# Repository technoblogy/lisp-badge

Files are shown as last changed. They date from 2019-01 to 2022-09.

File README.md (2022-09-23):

# Lisp Badge
A handheld computer with a self-contained keyboard and display that you can program in Lisp.

Version 6 updates the uLisp firmware to uLisp 4.3, adding support for arrays, and built-in documentation (see http://www.ulisp.com/show?41E0).

It also adds some extra key combinations to allow you to enter additional characters from the keyboard:

| Character | Combination |
| --- | --- |
| ~  | Shift+ESC |
| % | Shift+DEL |
| : | Shift+ENTER |
| ? | Shift+SPACE |

For information about building the Lisp Badge see: http://www.technoblogy.com/show?2AEE

For information about programming the Lisp badge see: http://www.ulisp.com/show?2L0C

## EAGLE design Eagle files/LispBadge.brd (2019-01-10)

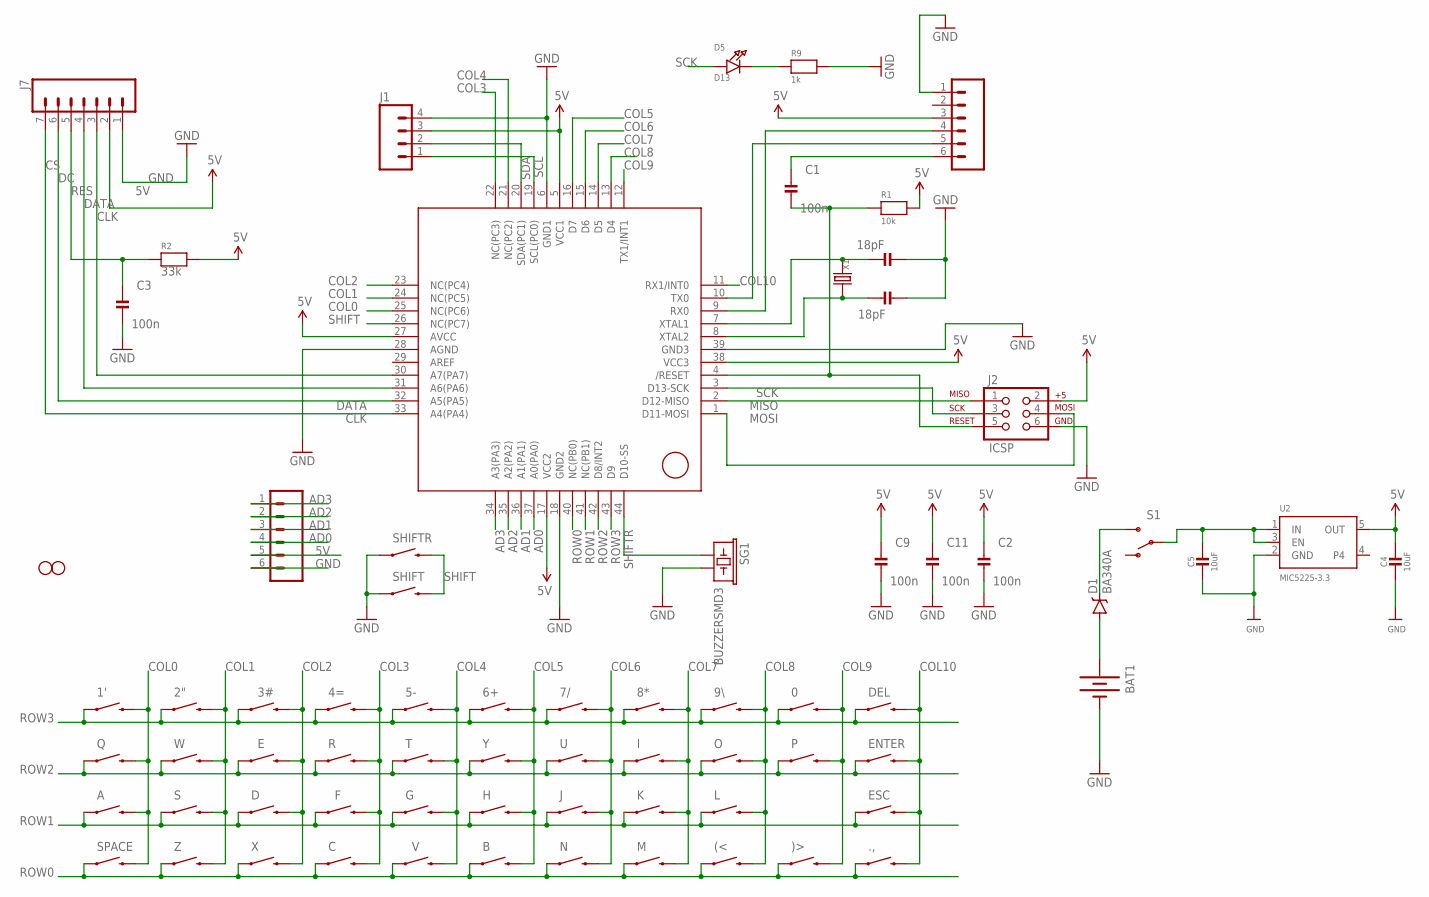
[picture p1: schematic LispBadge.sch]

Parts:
0, 1', 2", 3#, 4=, 5-, 6+, 7/, 8*, 9\\, .,: SWITCH-MOMENTARY-2PTH; TACTILE-PTH
(<: SWITCH-MOMENTARY-2PTH; TACTILE-PTH
)>: SWITCH-MOMENTARY-2PTH; TACTILE-PTH
A: SWITCH-MOMENTARY-2PTH; TACTILE-PTH
B: SWITCH-MOMENTARY-2PTH; TACTILE-PTH
BAT1: BATTERYAAA-KIT; BATTERY-AAA-KIT
C: SWITCH-MOMENTARY-2PTH; TACTILE-PTH
C1, C2, C3, C9, C11: 100n; _0805MP
C4, C5: 10uF; 0805-NO
C12, C13: 18pF; _0805MP
D: SWITCH-MOMENTARY-2PTH; TACTILE-PTH
D1: BA340A; SMA-DIODE
D5: D13; CHIPLED_0805_NOOUTLINE
DEL: SWITCH-MOMENTARY-2PTH; TACTILE-PTH
E: SWITCH-MOMENTARY-2PTH; TACTILE-PTH
ENTER: SWITCH-MOMENTARY-2PTH; TACTILE-PTH
ESC: SWITCH-MOMENTARY-2PTH; TACTILE-PTH
F: SWITCH-MOMENTARY-2PTH; TACTILE-PTH
G: SWITCH-MOMENTARY-2PTH; TACTILE-PTH
H: SWITCH-MOMENTARY-2PTH; TACTILE-PTH
I: SWITCH-MOMENTARY-2PTH; TACTILE-PTH
J: SWITCH-MOMENTARY-2PTH; TACTILE-PTH
J1: M04LONGPADS; 1X04_LONGPADS
J2: ICSP; 2X3
J7: M07; 1X07
JP1, JP11: M06LONGPADS; 1X06_LONGPADS
JP4, JP5: STAND-OFF
K: SWITCH-MOMENTARY-2PTH; TACTILE-PTH
L: SWITCH-MOMENTARY-2PTH; TACTILE-PTH
M: SWITCH-MOMENTARY-2PTH; TACTILE-PTH
N: SWITCH-MOMENTARY-2PTH; TACTILE-PTH
O: SWITCH-MOMENTARY-2PTH; TACTILE-PTH
P: SWITCH-MOMENTARY-2PTH; TACTILE-PTH
Q: SWITCH-MOMENTARY-2PTH; TACTILE-PTH
R: SWITCH-MOMENTARY-2PTH; TACTILE-PTH
R1: 10k; _0805MP
R2: 33k; _0805MP
R9: 1k; _0805MP
S: SWITCH-MOMENTARY-2PTH; TACTILE-PTH
S1: SWITCH-SPDTPTH; SWITCH-SPDT
SG1: BUZZERSMD3; BUZZER-CMT1102
SHIFT: SWITCH-MOMENTARY-2PTH; TACTILE-PTH
SHIFTR: SWITCH-MOMENTARY-2PTH; TACTILE-PTH
SPACE: SWITCH-MOMENTARY-2PTH; TACTILE-PTH
T: SWITCH-MOMENTARY-2PTH; TACTILE-PTH
U: SWITCH-MOMENTARY-2PTH; TACTILE-PTH
U2: MIC5225-3.3; SOT23-5
U3: ATMEGA1284P; TQFP44
V: SWITCH-MOMENTARY-2PTH; TACTILE-PTH
W: SWITCH-MOMENTARY-2PTH; TACTILE-PTH
X: SWITCH-MOMENTARY-2PTH; TACTILE-PTH
X1: CRYSTAL-0500290P1; 2P-SMD-5.0X3.2
Y: SWITCH-MOMENTARY-2PTH; TACTILE-PTH
Z: SWITCH-MOMENTARY-2PTH; TACTILE-PTH

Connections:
5V: C2.1, C4.1, C9.1, C11.1, J1.3, J2.2, J7.2, JP1.3, JP11.5, R1.2, R2.2, U2.5 (OUT), U3.5 (VCC1), U3.17 (VCC2), U3.27 (AVCC), U3.38 (VCC3)
AD0: JP11.4, U3.37 (A0(PA0))
AD1: JP11.3, U3.36 (A1(PA1))
AD2: JP11.2, U3.35 (A2(PA2))
AD3: JP11.1, U3.34 (A3(PA3))
CLK: J7.3, U3.30 (A7(PA7))
COL0: 1'.3 (2), A.3 (2), Q.3 (2), SPACE.3 (2), U3.25 (NC(PC6))
COL1: 2".3 (2), S.3 (2), U3.24 (NC(PC5)), W.3 (2), Z.3 (2)
COL2: 3#.3 (2), D.3 (2), E.3 (2), U3.23 (NC(PC4)), X.3 (2)
COL3: 4=.3 (2), C.3 (2), F.3 (2), R.3 (2), U3.22 (NC(PC3))
COL4: 5-.3 (2), G.3 (2), T.3 (2), U3.21 (NC(PC2)), V.3 (2)
COL5: 6+.3 (2), B.3 (2), H.3 (2), U3.16 (D7), Y.3 (2)
COL6: 7/.3 (2), J.3 (2), N.3 (2), U.3 (2), U3.15 (D6)
COL7: 8*.3 (2), I.3 (2), K.3 (2), M.3 (2), U3.14 (D5)
COL8: 9\\.3 (2), (<.3 (2), L.3 (2), O.3 (2), U3.13 (D4)
COL9: 0.3 (2), )>.3 (2), P.3 (2), U3.12 (TX1/INT1)
COL10: .,.3 (2), DEL.3 (2), ENTER.3 (2), ESC.3 (2), U3.11 (RX1/INT0)
CS: J7.7, U3.33 (A4(PA4))
DATA: J7.4, U3.31 (A6(PA6))
DC: J7.6, U3.32 (A5(PA5))
GND: BAT1.GND@1 (-), C2.2, C3.2, C4.2, C5.2, C9.2, C11.2, C12.1, C13.1, J1.4, J2.6, J7.1, JP1.1, JP11.6, R9.2, SG1.2, SHIFT.1, SHIFTR.1, U2.2 (GND), U3.6 (GND1), U3.18 (GND2), U3.28 (AGND), U3.39 (GND3)
MISO: J2.1, U3.2 (D12-MISO)
MOSI: J2.4, U3.1 (D11-MOSI)
unnamed: BAT1.PWR@1 (+), D1.A
unnamed: D1.C, S1.3 (S)
unnamed: D5.C, R9.1
unnamed: C5.1, S1.2, U2.1 (IN), U2.3 (EN)
unnamed: C13.2, U3.8 (XTAL2), X1.2
unnamed: C12.2, U3.7 (XTAL1), X1.1
unnamed: C1.2, J2.5, R1.1, U3.4 (/RESET)
unnamed: C1.1, JP1.6
RES: C3.1, J7.5, R2.1
ROW0: (<.1, )>.1, .,.1, B.1, C.1, M.1, N.1, SPACE.1, U3.40 (NC(PB0)), V.1, X.1, Z.1
ROW1: A.1, D.1, ESC.1, F.1, G.1, H.1, J.1, K.1, L.1, S.1, U3.41 (NC(PB1))
ROW2: E.1, ENTER.1, I.1, O.1, P.1, Q.1, R.1, T.1, U.1, U3.42 (D8/INT2), W.1, Y.1
ROW3: 0.1, 1'.1, 2".1, 3#.1, 4=.1, 5-.1, 6+.1, 7/.1, 8*.1, 9\\.1, DEL.1, U3.43 (D9)
RX-I: JP1.4, U3.9 (RX0)
SCK: D5.A, J2.3, U3.3 (D13-SCK)
SCL: J1.1, U3.19 (SCL(PC0))
SDA: J1.2, U3.20 (SDA(PC1))
SHIFT: SHIFT.3 (2), SHIFTR.3 (2), U3.26 (NC(PC7))
SHIFTR: SG1.1, U3.44 (D10-SS)
TX-O: JP1.5, U3.10 (TX0)

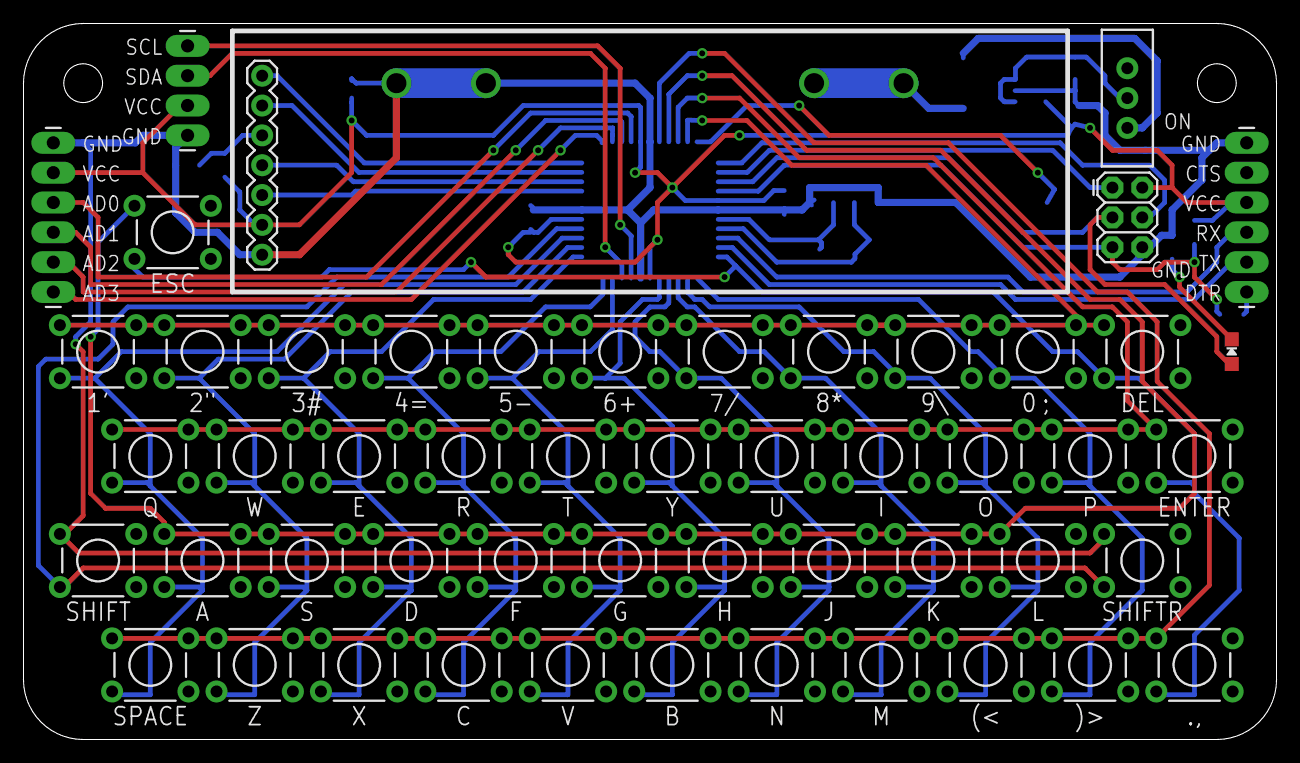
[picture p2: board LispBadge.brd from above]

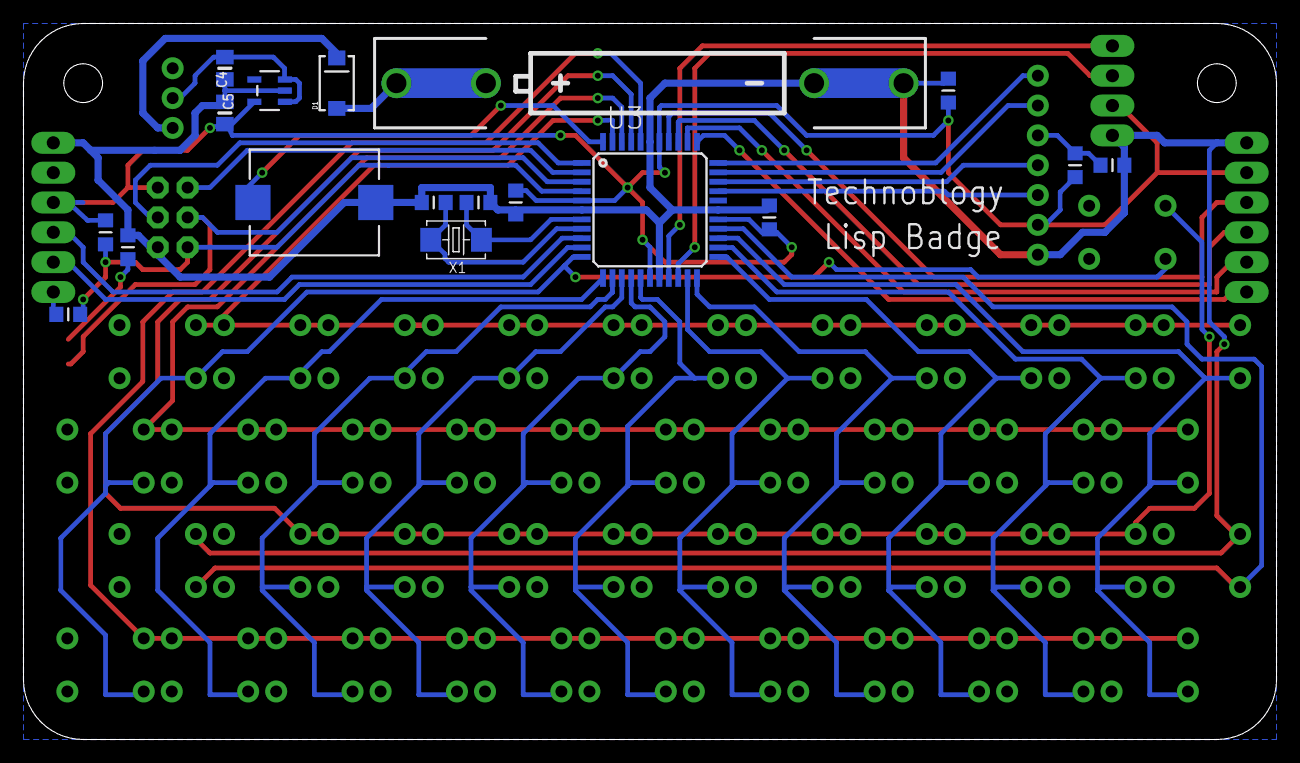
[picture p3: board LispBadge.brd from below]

Board: 2 copper layers, 106.7 x 61.0 mm, 72 parts (18 on the bottom side), 43 nets.

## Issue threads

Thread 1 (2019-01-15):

Schematic for those who are not using Eagle

fdufnews, 2019-01-15:
Hi,
Thanks a lot for this design but can you put a schematic in pdf format for those that are not using eagle.
When comparing the code in this repo and the schematic on technoblogy it seems there are differences (on shiftr for example).
A fast search with a text editor seems to confirm that shiftr is connected to D10-SS. Am I right?
Best regards
fdufnews

technoblogy, 2019-01-15:
The left and right SHIFT keys both connect between PC7 and GND. The label SHIFTR on D10 on the Eagle schematic is a mistake, and should be removed.

The schematic on Technoblogy was generated from the Eagle schematic, and then tidied up by hand. It corrects some errors that don't affect the PCB. Which one would you like as a PDF?

fdufnews, 2019-01-15:
Ok, thanks you for the answer.
So the second part of the test at line 3882 is no more necessary
```
  // Check rows and shift keys
  shift = ((PINC & 1<<PINC7) && (PINB & 1<<PINB4)) ? 0 : 1;
```
I am analysing the code because I want to use the keyboard of an Xbox chatpad and the matrix is different from the one you are using.

technoblogy, 2019-01-15:
You’re correct. The previous version of the circuit had the SHIFT keys on two separate inputs, but I decided to add a piezo speaker on PB4, so that line should change to:

  shift = (PINC & 1<<PINC7) ? 0 : 1;

Also, remove this line in InitKybd():

  PORTB = PORTB | 1<<PINB4;

Thanks for spotting that. I’ll update the code.

Regards,
David

+------------------------------------------------------------+
David Johnson-Davies, Human-Computer Interface Ltd
17 Signet Court, Swanns Road, Cambridge, CB5 8LA, England.

Tel: +44 1223 314934, Fax: +44 1223 462562
Email: david@interface.co.uk, Web: http://www.interface.co.uk/
+------------------------------------------------------------+

Closed 2019-01-15.

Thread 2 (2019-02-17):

playNote() not working

Odingod, 2019-02-17:
Hi

 and thanks for the design!

I noticed that the note function isn't working. I checked the code and found this
```
if (pin == 14) {
    DDRD = DDRD | 1<<DDD6; // PD6 (Arduino D14) as output
    TCCR2A = 0<<COM2A0 | 1<<COM2B0 | 2<<WGM20; // Toggle OC2B on match
  } else if (pin == 15) {
    DDRD = DDRD | 1<<DDD7; // PD7 (Arduino D15) as output
    TCCR2A = 1<<COM2A0 | 0<<COM2B0 | 2<<WGM20; // Toggle OC2A on match
  } else error(PSTR("'note' pin not supported"));
```

Shouldn't there be pin PB4 in there?

I tried changing it to this
```
  if (pin == 10) {
    DDRB = DDRB | 1<<DDB4; // PB4 (Arduino D10) as output
    TCCR2A = 1<<COM2A0 | 0<<COM2B0 | 2<<WGM20; // Toggle OC2A on match
  } else error(PSTR("'note' pin not supported"));
```

but it didn't work. I'm not that familiar with the registers used so that might be the problem.

The symptoms of this are, that the keyboard stops working in both cases when I either call (note 14 0 4) or (note 10 0 4). The serial communication works fine though.

technoblogy, 2019-02-17:
Unfortunately you can't use the uLisp **note** function with the Lisp Badge because on the ATmega1284P **note** uses pins PD6 or PD7, and these are used for the keyboard on the Lisp Badge. Perhaps this could be solved in a future version of the PCB. In the meantime Version 1c allows you to play a "beep" through the speaker with (princ #\beep).

Odingod, 2019-02-17:
Okay, I'll write a simpler note function with tone.

Thanks for the quick response and for the badge!
P.S.
I couldn't get the beep working, I get both unknown character and incomplete list errors with that.

technoblogy, 2019-02-17:
Sorry, I meant: (princ #\bell).

PS Glad you got the badge working; I'd love to see a photo of it!

Odingod, 2019-02-17:
Here's a bad photo http://i65.tinypic.com/11ioies.jpg. The screen is not blurry at all.

technoblogy, 2019-02-17:
Great! Nice job.

Closed 2019-02-17.

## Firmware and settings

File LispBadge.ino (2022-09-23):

/* Lisp Badge - uLisp 4.3
   David Johnson-Davies - www.technoblogy.com - 22nd September 2022

   Licensed under the MIT license: https://opensource.org/licenses/MIT
*/

// Lisp Library
const char LispLibrary[] PROGMEM = "";

// Compile options

#define checkoverflow
// #define resetautorun
#define printfreespace
#define serialmonitor
// #define printgcs
// #define sdcardsupport
// #define lisplibrary

// Includes

// #include "LispLibrary.h"
#include <avr/sleep.h>
#include <setjmp.h>
#include <SPI.h>
#include <limits.h>
#include <EEPROM.h>

#if defined(sdcardsupport)
#include <SD.h>
#define SDSIZE 172
#else
#define SDSIZE 0
#endif

// Workspace - sizes in bytes
#define WORDALIGNED __attribute__((aligned (2)))
#define OBJECTALIGNED __attribute__((aligned (4)))
#define BUFFERSIZE 21                     /* longest builtin name + 1 */

#if defined(__AVR_ATmega1284P__)
  #include "optiboot.h"
  #define WORKSPACESIZE (2848-SDSIZE)     /* Objects (4*bytes) */
//  #define EEPROMSIZE 4096                 /* Bytes */
  #define FLASHWRITESIZE 16384            /* Bytes */
  #define CODESIZE 96                     /* Bytes <= 256 */
  #define STACKDIFF 320
  #define CPU_ATmega1284P

#else
#error "Board not supported!"
#endif

// C Macros

#define nil                NULL
#define car(x)             (((object *) (x))->car)
#define cdr(x)             (((object *) (x))->cdr)

#define first(x)           (((object *) (x))->car)
#define second(x)          (car(cdr(x)))
#define cddr(x)            (cdr(cdr(x)))
#define third(x)           (car(cdr(cdr(x))))

#define push(x, y)         ((y) = cons((x),(y)))
#define pop(y)             ((y) = cdr(y))

#define integerp(x)        ((x) != NULL && (x)->type == NUMBER)
#define symbolp(x)         ((x) != NULL && (x)->type == SYMBOL)
#define stringp(x)         ((x) != NULL && (x)->type == STRING)
#define characterp(x)      ((x) != NULL && (x)->type == CHARACTER)
#define arrayp(x)          ((x) != NULL && (x)->type == ARRAY)
#define streamp(x)         ((x) != NULL && (x)->type == STREAM)

#define mark(x)            (car(x) = (object *)(((uintptr_t)(car(x))) | MARKBIT))
#define unmark(x)          (car(x) = (object *)(((uintptr_t)(car(x))) & ~MARKBIT))
#define marked(x)          ((((uintptr_t)(car(x))) & MARKBIT) != 0)
#define MARKBIT            1

#define setflag(x)         (Flags = Flags | 1<<(x))
#define clrflag(x)         (Flags = Flags & ~(1<<(x)))
#define tstflag(x)         (Flags & 1<<(x))

#define issp(x)            (x == ' ' || x == '\n' || x == '\r' || x == '\t')
#define longsymbolp(x)     (((x)->name & 0x03) == 0)
#define twist(x)           ((uint16_t)((x)<<2) | (((x) & 0xC000)>>14))
#define untwist(x)         (((x)>>2 & 0x3FFF) | ((x) & 0x03)<<14)
#define PACKEDS            17600
#define BUILTINS           64000

// Code marker stores start and end of code block (max 256 bytes)
#define startblock(x)      ((x->integer) & 0xFF)
#define endblock(x)        ((x->integer) >> 8 & 0xFF)

#define SDCARD_SS_PIN 10

#if defined(CPU_ATmega4809)
#define PROGMEM
#define PSTR(s) (s)
#endif

// Constants

const int TRACEMAX = 3; // Number of traced functions
enum type { ZZERO=0, SYMBOL=2, CODE=4, NUMBER=6, STREAM=8, CHARACTER=10, ARRAY=12, STRING=14, PAIR=16 };  // ARRAY STRING and PAIR must be last
enum token { UNUSED, BRA, KET, QUO, DOT };
enum stream { SERIALSTREAM, I2CSTREAM, SPISTREAM, SDSTREAM, STRINGSTREAM };

// Stream names used by printobject
const char serialstream[] PROGMEM = "serial";
const char i2cstream[] PROGMEM = "i2c";
const char spistream[] PROGMEM = "spi";
const char sdstream[] PROGMEM = "sd";
PGM_P const streamname[] PROGMEM = {serialstream, i2cstream, spistream, sdstream};

// Typedefs

typedef unsigned int symbol_t;

typedef struct sobject {
  union {
    struct {
      sobject *car;
      sobject *cdr;
    };
    struct {
      unsigned int type;
      union {
        symbol_t name;
        int integer;
        int chars; // For strings
      };
    };
  };
} object;

typedef object *(*fn_ptr_type)(object *, object *);
typedef void (*mapfun_t)(object *, object **);
typedef int (*intfn_ptr_type)(int w, int x, int y, int z);

typedef const struct {
  const char *string;
  fn_ptr_type fptr;
  uint8_t minmax;
  const char *doc;
} tbl_entry_t;

typedef int (*gfun_t)();
typedef void (*pfun_t)(char);

enum builtin_t { NIL, TEE, NOTHING, OPTIONAL, INITIALELEMENT, ELEMENTTYPE, BIT, AMPREST, LAMBDA, LET,
LETSTAR, CLOSURE, PSTAR, SPECIAL_FORMS, QUOTE, OR, DEFUN, DEFVAR, SETQ, LOOP, RETURN, PUSH, POP, INCF,
DECF, SETF, DOLIST, DOTIMES, TRACE, UNTRACE, FORMILLIS, TIME, WITHSERIAL, WITHI2C, WITHSPI, WITHSDCARD,
DEFCODE, TAIL_FORMS, PROGN, IF, COND, WHEN, UNLESS, CASE, AND, HELP, FUNCTIONS, NOT, NULLFN, CONS, ATOM,
LISTP, CONSP, SYMBOLP, BOUNDP, SETFN, STREAMP, EQ, CAR, FIRST, CDR, REST, CAAR, CADR, SECOND, CDAR, CDDR,
CAAAR, CAADR, CADAR, CADDR, THIRD, CDAAR, CDADR, CDDAR, CDDDR, LENGTH, ARRAYDIMENSIONS, LIST, MAKEARRAY,
REVERSE, NTH, AREF, ASSOC, MEMBER, APPLY, FUNCALL, APPEND, MAPC, MAPCAR, MAPCAN, ADD, SUBTRACT, MULTIPLY,
DIVIDE, TRUNCATE, MOD, ONEPLUS, ONEMINUS, ABS, RANDOM, MAXFN, MINFN, NOTEQ, NUMEQ, LESS, LESSEQ, GREATER,
GREATEREQ, PLUSP, MINUSP, ZEROP, ODDP, EVENP, INTEGERP, NUMBERP, CHAR, CHARCODE, CODECHAR, CHARACTERP,
STRINGP, STRINGEQ, STRINGLESS, STRINGGREATER, SORT, STRINGFN, CONCATENATE, SUBSEQ, READFROMSTRING,
PRINCTOSTRING, PRIN1TOSTRING, LOGAND, LOGIOR, LOGXOR, LOGNOT, ASH, LOGBITP, EVAL, GLOBALS, LOCALS,
MAKUNBOUND, BREAK, READ, PRIN1, PRINT, PRINC, TERPRI, READBYTE, READLINE, WRITEBYTE, WRITESTRING,
WRITELINE, RESTARTI2C, GC, ROOM, SAVEIMAGE, LOADIMAGE, CLS, PINMODE, DIGITALREAD, DIGITALWRITE,
ANALOGREAD, ANALOGREFERENCE, ANALOGREADRESOLUTION, ANALOGWRITE, DACREFERENCE, DELAY, MILLIS, SLEEP, NOTE,
REGISTER, EDIT, PPRINT, PPRINTALL, FORMAT, REQUIRE, LISTLIBRARY, DOCUMENTATION, PLOT, PLOT3D, GLYPHPIXEL,
PLOTPIXEL, FILLSCREEN, KEYWORDS, 
#if defined(CPU_ATmega1284P)
K_HIGH, K_LOW, K_INPUT, K_INPUT_PULLUP, K_OUTPUT, K_DEFAULT, K_INTERNAL1V1, K_INTERNAL2V56, K_EXTERNAL,
#endif
USERFUNCTIONS, ENDFUNCTIONS, SET_SIZE = INT_MAX };

// Global variables

object Workspace[WORKSPACESIZE] OBJECTALIGNED;
#if defined(CODESIZE)
uint8_t MyCode[CODESIZE] WORDALIGNED; // Must be even
#endif

jmp_buf exception;
unsigned int Freespace = 0;
object *Freelist;
unsigned int I2Ccount;
unsigned int TraceFn[TRACEMAX];
unsigned int TraceDepth[TRACEMAX];

object *GlobalEnv;
object *GCStack = NULL;
object *GlobalString;
object *GlobalStringTail;
int GlobalStringIndex = 0;
uint8_t PrintCount = 0;
uint8_t BreakLevel = 0;
char LastChar = 0;
char LastPrint = 0;
uint16_t RandomSeed;

// Flags
enum flag { PRINTREADABLY, RETURNFLAG, ESCAPE, EXITEDITOR, LIBRARYLOADED, NOESC, NOECHO };
volatile uint8_t Flags = 0b00001; // PRINTREADABLY set by default

// Forward references
object *tee;
void pfstring (PGM_P s, pfun_t pfun);

// Error handling

void errorsub (symbol_t fname, PGM_P string) {
  pfl(pserial); pfstring(PSTR("Error: "), pserial);
  if (fname != sym(NIL)) {
    pserial('\'');
    psymbol(fname, pserial);
    pserial('\''); pserial(' ');
  }
  pfstring(string, pserial);
}

void errorsym (symbol_t fname, PGM_P string, object *symbol) {
  errorsub(fname, string);
  pserial(':'); pserial(' ');
  printobject(symbol, pserial);
  errorend();
}

void errorsym2 (symbol_t fname, PGM_P string) {
  errorsub(fname, string);
  errorend();
}

void error (builtin_t fname, PGM_P string, object *symbol) {
  errorsym(sym(fname), string, symbol);
}

void error2 (builtin_t fname, PGM_P string) {
  errorsym2(sym(fname), string);
}

void errorend () { pln(pserial); GCStack = NULL; longjmp(exception, 1); }

void formaterr (object *formatstr, PGM_P string, uint8_t p) {
  pln(pserial); indent(4, ' ', pserial); printstring(formatstr, pserial); pln(pserial);
  indent(p+5, ' ', pserial); pserial('^');
  error2(FORMAT, string);
  pln(pserial);
  GCStack = NULL;
  longjmp(exception, 1);
}

// Save space as these are used multiple times
const char notanumber[] PROGMEM = "argument is not a number";
const char notaninteger[] PROGMEM = "argument is not an integer";
const char notastring[] PROGMEM = "argument is not a string";
const char notalist[] PROGMEM = "argument is not a list";
const char notasymbol[] PROGMEM = "argument is not a symbol";
const char notproper[] PROGMEM = "argument is not a proper list";
const char toomanyargs[] PROGMEM = "too many arguments";
const char toofewargs[] PROGMEM = "too few arguments";
const char noargument[] PROGMEM = "missing argument";
const char nostream[] PROGMEM = "missing stream argument";
const char overflow[] PROGMEM = "arithmetic overflow";
const char divisionbyzero[] PROGMEM = "division by zero";
const char indexnegative[] PROGMEM = "index can't be negative";
const char invalidarg[] PROGMEM = "invalid argument";
const char invalidkey[] PROGMEM = "invalid keyword";
const char illegalclause[] PROGMEM = "illegal clause";
const char invalidpin[] PROGMEM = "invalid pin";
const char oddargs[] PROGMEM = "odd number of arguments";
const char indexrange[] PROGMEM = "index out of range";
const char canttakecar[] PROGMEM = "can't take car";
const char canttakecdr[] PROGMEM = "can't take cdr";
const char unknownstreamtype[] PROGMEM = "unknown stream type";

// Set up workspace

void initworkspace () {
  Freelist = NULL;
  for (int i=WORKSPACESIZE-1; i>=0; i--) {
    object *obj = &Workspace[i];
    car(obj) = NULL;
    cdr(obj) = Freelist;
    Freelist = obj;
    Freespace++;
  }
}

object *myalloc () {
  if (Freespace == 0) error2(NIL, PSTR("no room"));
  object *temp = Freelist;
  Freelist = cdr(Freelist);
  Freespace--;
  return temp;
}

inline void myfree (object *obj) {
  car(obj) = NULL;
  cdr(obj) = Freelist;
  Freelist = obj;
  Freespace++;
}

// Make each type of object

object *number (int n) {
  object *ptr = myalloc();
  ptr->type = NUMBER;
  ptr->integer = n;
  return ptr;
}

object *character (uint8_t c) {
  object *ptr = myalloc();
  ptr->type = CHARACTER;
  ptr->chars = c;
  return ptr;
}

object *cons (object *arg1, object *arg2) {
  object *ptr = myalloc();
  ptr->car = arg1;
  ptr->cdr = arg2;
  return ptr;
}

object *symbol (symbol_t name) {
  object *ptr = myalloc();
  ptr->type = SYMBOL;
  ptr->name = name;
  return ptr;
}

inline object *bsymbol (builtin_t name) {
  return intern(twist(name+BUILTINS));
}

object *codehead (int entry) {
  object *ptr = myalloc();
  ptr->type = CODE;
  ptr->integer = entry;
  return ptr;
}

object *intern (symbol_t name) {
  for (int i=0; i<WORKSPACESIZE; i++) {
    object *obj = &Workspace[i];
    if (obj->type == SYMBOL && obj->name == name) return obj;
  }
  return symbol(name);
}

bool eqsymbols (object *obj, char *buffer) {
  object *arg = cdr(obj);
  int i = 0;
  while (!(arg == NULL && buffer[i] == 0)) {
    if (arg == NULL || buffer[i] == 0 || arg->chars != (buffer[i]<<8 | buffer[i+1])) return false;
    arg = car(arg);
    i = i + 2;
  }
  return true;
}

object *internlong (char *buffer) {
  for (int i=0; i<WORKSPACESIZE; i++) {
    object *obj = &Workspace[i];
    if (obj->type == SYMBOL && longsymbolp(obj) && eqsymbols(obj, buffer)) return obj;
  }
  object *obj = lispstring(buffer);
  obj->type = SYMBOL;
  return obj;
}

object *stream (uint8_t streamtype, uint8_t address) {
  object *ptr = myalloc();
  ptr->type = STREAM;
  ptr->integer = streamtype<<8 | address;
  return ptr;
}

object *newstring () {
  object *ptr = myalloc();
  ptr->type = STRING;
  ptr->chars = 0;
  return ptr;
}

// Garbage collection

void markobject (object *obj) {
  MARK:
  if (obj == NULL) return;
  if (marked(obj)) return;

  object* arg = car(obj);
  unsigned int type = obj->type;
  mark(obj);

  if (type >= PAIR || type == ZZERO) { // cons
    markobject(arg);
    obj = cdr(obj);
    goto MARK;
  }

  if (type == ARRAY) {
    obj = cdr(obj);
    goto MARK;
  }

  if ((type == STRING) || (type == SYMBOL && longsymbolp(obj))) {
    obj = cdr(obj);
    while (obj != NULL) {
      arg = car(obj);
      mark(obj);
      obj = arg;
    }
  }
}

void sweep () {
  Freelist = NULL;
  Freespace = 0;
  for (int i=WORKSPACESIZE-1; i>=0; i--) {
    object *obj = &Workspace[i];
    if (!marked(obj)) myfree(obj); else unmark(obj);
  }
}

void gc (object *form, object *env) {
  #if defined(printgcs)
  int start = Freespace;
  #endif
  markobject(tee);
  markobject(GlobalEnv);
  markobject(GCStack);
  markobject(form);
  markobject(env);
  sweep();
  #if defined(printgcs)
  pfl(pserial); pserial('{'); pint(Freespace - start, pserial); pserial('}');
  #endif
}

// Compact image

void movepointer (object *from, object *to) {
  for (int i=0; i<WORKSPACESIZE; i++) {
    object *obj = &Workspace[i];
    unsigned int type = (obj->type) & ~MARKBIT;
    if (marked(obj) && (type >= ARRAY || type==ZZERO || (type == SYMBOL && longsymbolp(obj)))) {
      if (car(obj) == (object *)((uintptr_t)from | MARKBIT))
        car(obj) = (object *)((uintptr_t)to | MARKBIT);
      if (cdr(obj) == from) cdr(obj) = to;
    }
  }
  // Fix strings and long symbols
  for (int i=0; i<WORKSPACESIZE; i++) {
    object *obj = &Workspace[i];
    if (marked(obj)) {
      unsigned int type = (obj->type) & ~MARKBIT;
      if (type == STRING || (type == SYMBOL && longsymbolp(obj))) {
        obj = cdr(obj);
        while (obj != NULL) {
          if (cdr(obj) == to) cdr(obj) = from;
          obj = (object *)((uintptr_t)(car(obj)) & ~MARKBIT);
        }
      }
    }
  }
}

uintptr_t compactimage (object **arg) {
  markobject(tee);
  markobject(GlobalEnv);
  markobject(GCStack);
  object *firstfree = Workspace;
  while (marked(firstfree)) firstfree++;
  object *obj = &Workspace[WORKSPACESIZE-1];
  while (firstfree < obj) {
    if (marked(obj)) {
      car(firstfree) = car(obj);
      cdr(firstfree) = cdr(obj);
      unmark(obj);
      movepointer(obj, firstfree);
      if (GlobalEnv == obj) GlobalEnv = firstfree;
      if (GCStack == obj) GCStack = firstfree;
      if (*arg == obj) *arg = firstfree;
      while (marked(firstfree)) firstfree++;
    }
    obj--;
  }
  sweep();
  return firstfree - Workspace;
}

// Make SD card filename

char *MakeFilename (object *arg, char *buffer) {
  int max = BUFFERSIZE-1;
  int i = 0;
  do {
    char c = nthchar(arg, i);
    if (c == '\0') break;
    buffer[i++] = c;
  } while (i<max);
  buffer[i] = '\0';
  return buffer;
}

// Save-image and load-image

#if defined(sdcardsupport)
void SDWriteInt (File file, int data) {
  file.write(data & 0xFF); file.write(data>>8 & 0xFF);
}

int SDReadInt (File file) {
  uint8_t b0 = file.read(); uint8_t b1 = file.read();
  return b0 | b1<<8;
}
#elif defined(FLASHWRITESIZE)
#if defined (CPU_ATmega1284P)
// save-image area is the 16K bytes (64 256-byte pages) from 0x1bc00 to 0x1fc00
const uint32_t BaseAddress = 0x1bc00;
uint8_t FlashCheck() {
  return 0;
}

void FlashWriteInt (uint32_t *addr, int data) {
  if (((*addr) & 0xFF) == 0) optiboot_page_erase(BaseAddress + ((*addr) & 0xFF00));
  optiboot_page_fill(BaseAddress + *addr, data);
  if (((*addr) & 0xFF) == 0xFE) optiboot_page_write(BaseAddress + ((*addr) & 0xFF00));
  (*addr)++; (*addr)++;
}

void FlashEndWrite (uint32_t *addr) {
  if (((*addr) & 0xFF) != 0) optiboot_page_write((BaseAddress + ((*addr) & 0xFF00)));
}

uint8_t FlashReadByte (uint32_t *addr) {
  return pgm_read_byte_far(BaseAddress + (*addr)++);
}

int FlashReadInt (uint32_t *addr) {
  int data = pgm_read_word_far(BaseAddress + *addr);
  (*addr)++; (*addr)++;
  return data;
}
#elif defined (CPU_AVR128DX48)
// save-image area is the 16K bytes (32 512-byte pages) from 0x1c000 to 0x20000
const uint32_t BaseAddress = 0x1c000;
uint8_t FlashCheck() {
  return Flash.checkWritable();
}

void FlashWriteInt (uint32_t *addr, int data) {
  if (((*addr) & 0x1FF) == 0) Flash.erasePage(BaseAddress + ((*addr) & 0xFE00));
  Flash.writeWord(BaseAddress + *addr, data);
  (*addr)++; (*addr)++;
}

void FlashEndWrite (uint32_t *addr) {
  (void) addr;
}

uint8_t FlashReadByte (uint32_t *addr) {
  return Flash.readByte(BaseAddress + (*addr)++);
}

int FlashReadInt (uint32_t *addr) {
  int data = Flash.readWord(BaseAddress + *addr);
  (*addr)++; (*addr)++;
  return data;
}
#endif
#else
void EEPROMWriteInt (unsigned int *addr, int data) {
  EEPROM.write((*addr)++, data & 0xFF); EEPROM.write((*addr)++, data>>8 & 0xFF);
}

int EEPROMReadInt (unsigned int *addr) {
  uint8_t b0 = EEPROM.read((*addr)++); uint8_t b1 = EEPROM.read((*addr)++);
  return b0 | b1<<8;
}
#endif

unsigned int saveimage (object *arg) {
  unsigned int imagesize = compactimage(&arg);
#if defined(sdcardsupport)
  SD.begin(SDCARD_SS_PIN);
  File file;
  if (stringp(arg)) {
    char buffer[BUFFERSIZE];
    file = SD.open(MakeFilename(arg, buffer), O_RDWR | O_CREAT | O_TRUNC);
    if (!file) error2(SAVEIMAGE, PSTR("problem saving to SD card or invalid filename"));
    arg = NULL;
  } else if (arg == NULL || listp(arg)) {
    file = SD.open("/ULISP.IMG", O_RDWR | O_CREAT | O_TRUNC);
    if (!file) error2(SAVEIMAGE, PSTR("problem saving to SD card"));
  }
  else error(SAVEIMAGE, invalidarg, arg);
  SDWriteInt(file, (uintptr_t)arg);
  SDWriteInt(file, imagesize);
  SDWriteInt(file, (uintptr_t)GlobalEnv);
  SDWriteInt(file, (uintptr_t)GCStack);
  #if defined(CODESIZE)
  for (int i=0; i<CODESIZE; i++) file.write(MyCode[i]);
  #endif
  for (unsigned int i=0; i<imagesize; i++) {
    object *obj = &Workspace[i];
    SDWriteInt(file, (uintptr_t)car(obj));
    SDWriteInt(file, (uintptr_t)cdr(obj));
  }
  file.close();
  return imagesize;
#elif defined(FLASHWRITESIZE)
  if (!(arg == NULL || listp(arg))) error(SAVEIMAGE, invalidarg, arg);
  if (FlashCheck()) error2(SAVEIMAGE, PSTR("flash write not supported"));
  // Save to Flash
  int bytesneeded = 10 + CODESIZE + imagesize*4;
  if (bytesneeded > FLASHWRITESIZE) error(SAVEIMAGE, PSTR("image too large"), number(imagesize));
  uint32_t addr = 0;
  FlashWriteInt(&addr, (uintptr_t)arg);
  FlashWriteInt(&addr, imagesize);
  FlashWriteInt(&addr, (uintptr_t)GlobalEnv);
  FlashWriteInt(&addr, (uintptr_t)GCStack);
  #if defined(CODESIZE)
  for (int i=0; i<CODESIZE/2; i++) FlashWriteInt(&addr, MyCode[i*2] | MyCode[i*2+1]<<8);
  #endif
  for (unsigned int i=0; i<imagesize; i++) {
    object *obj = &Workspace[i];
    FlashWriteInt(&addr, (uintptr_t)car(obj));
    FlashWriteInt(&addr, (uintptr_t)cdr(obj));
  }
  FlashEndWrite(&addr);
  return imagesize;
#else
  if (!(arg == NULL || listp(arg))) error(SAVEIMAGE, invalidarg, arg);
  int bytesneeded = imagesize*4 + 10;
  if (bytesneeded > EEPROMSIZE) error(SAVEIMAGE, PSTR("image too large"), number(imagesize));
  unsigned int addr = 0;
  EEPROMWriteInt(&addr, (unsigned int)arg);
  EEPROMWriteInt(&addr, imagesize);
  EEPROMWriteInt(&addr, (unsigned int)GlobalEnv);
  EEPROMWriteInt(&addr, (unsigned int)GCStack);
  for (unsigned int i=0; i<imagesize; i++) {
    object *obj = &Workspace[i];
    EEPROMWriteInt(&addr, (uintptr_t)car(obj));
    EEPROMWriteInt(&addr, (uintptr_t)cdr(obj));
  }
  return imagesize;
#endif
}

unsigned int loadimage (object *arg) {
#if defined(sdcardsupport)
  SD.begin(SDCARD_SS_PIN);
  File file;
  if (stringp(arg)) {
    char buffer[BUFFERSIZE];
    file = SD.open(MakeFilename(arg, buffer));
    if (!file) error2(LOADIMAGE, PSTR("problem loading from SD card or invalid filename"));
  }
  else if (arg == NULL) {
    file = SD.open("/ULISP.IMG");
    if (!file) error2(LOADIMAGE, PSTR("problem loading from SD card"));
  }
  else error(LOADIMAGE, invalidarg, arg);
  SDReadInt(file);
  unsigned int imagesize = SDReadInt(file);
  GlobalEnv = (object *)SDReadInt(file);
  GCStack = (object *)SDReadInt(file);
  #if defined(CODESIZE)
  for (int i=0; i<CODESIZE; i++) MyCode[i] = file.read();
  #endif
  for (unsigned int i=0; i<imagesize; i++) {
    object *obj = &Workspace[i];
    car(obj) = (object *)SDReadInt(file);
    cdr(obj) = (object *)SDReadInt(file);
  }
  file.close();
  gc(NULL, NULL);
  return imagesize;
#elif defined(FLASHWRITESIZE)
  (void) arg;
  if (FlashCheck()) error2(SAVEIMAGE, PSTR("flash write not supported"));
  uint32_t addr = 0;
  FlashReadInt(&addr); // Skip eval address
  unsigned int imagesize = FlashReadInt(&addr);
  if (imagesize == 0 || imagesize == 0xFFFF) error2(LOADIMAGE, PSTR("no saved image"));
  GlobalEnv = (object *)FlashReadInt(&addr);
  GCStack = (object *)FlashReadInt(&addr);
  #if defined(CODESIZE)
  for (int i=0; i<CODESIZE; i++) MyCode[i] = FlashReadByte(&addr);
  #endif
  for (unsigned int i=0; i<imagesize; i++) {
    object *obj = &Workspace[i];
    car(obj) = (object *)FlashReadInt(&addr);
    cdr(obj) = (object *)FlashReadInt(&addr);
  }
  gc(NULL, NULL);
  return imagesize;
#else
  (void) arg;
  unsigned int addr = 2; // Skip eval address
  unsigned int imagesize = EEPROMReadInt(&addr);
  if (imagesize == 0 || imagesize == 0xFFFF) error2(LOADIMAGE, PSTR("no saved image"));
  GlobalEnv = (object *)EEPROMReadInt(&addr);
  GCStack = (object *)EEPROMReadInt(&addr);
  for (unsigned int i=0; i<imagesize; i++) {
    object *obj = &Workspace[i];
    car(obj) = (object *)EEPROMReadInt(&addr);
    cdr(obj) = (object *)EEPROMReadInt(&addr);
  }
  gc(NULL, NULL);
  return imagesize;
#endif
}
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
void loop () {
  if (!setjmp(exception)) {
    #if defined(resetautorun)
    volatile int autorun = 12; // Fudge to keep code size the same
    #else
    volatile int autorun = 13;
    #endif
    if (autorun == 12) autorunimage();
  }
  // Come here after error
  delay(100); while (Serial.available()) Serial.read();
  clrflag(NOESC); BreakLevel = 0; nonote(4);
  for (int i=0; i<TRACEMAX; i++) TraceDepth[i] = 0;
  #if defined(sdcardsupport)
  SDpfile.close(); SDgfile.close();
  #endif
  #if defined(lisplibrary)
  if (!tstflag(LIBRARYLOADED)) { setflag(LIBRARYLOADED); loadfromlibrary(NULL); }
  #endif
  repl(NULL);
}

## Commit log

2019-01-10 Version 1 - 10th January 2019
    [LispBadge.brd, LispBadge.sch]
2019-01-11 Version 1a - 11th January 2019
    Fixed typo in plot.
    [LispBadge.ino]
2019-01-12 Version 1b - 12th January 2019
    Fix compile error.
    [LispBadge.ino]
2019-02-07 Version 1c - 7th February 2019
    Fixes a keyboard problem on some boards, and adds beep to the piezo speaker.
    [LispBadge.ino]

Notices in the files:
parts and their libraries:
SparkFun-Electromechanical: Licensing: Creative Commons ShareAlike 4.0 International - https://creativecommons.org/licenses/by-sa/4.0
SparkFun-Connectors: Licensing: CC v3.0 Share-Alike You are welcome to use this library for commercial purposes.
